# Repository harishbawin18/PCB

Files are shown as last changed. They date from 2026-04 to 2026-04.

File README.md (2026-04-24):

# PPG Watch PCB Design 

## Project Overview

This project presents the design and routing of a **Photoplethysmography (PPG) based wearable watch PCB**, developed using **KiCad 9.0**.
The PCB is designed to acquire pulse signals using an optical PPG sensor and support wearable health monitoring applications.
---
## Key Features
* Compact **wearable watch-size PCB layout**
* Designed using **KiCad 9.0**
* **Single-layer component placement**
* **Multi-layer routing** for optimized signal flow
* Clear **reference designators** (U1, R1, C1, etc.)
* Dedicated **power management section**
* Sensor integration for **PPG signal acquisition**
* Optimized routing for **noise reduction**
* Organized schematic hierarchy
---
## System Description
The PPG watch system includes the following major functional blocks:
### 1. PPG Sensor Module

* Optical PPG sensor detects blood volume changes.
* Uses LED light reflection technique.
* Generates analog signals corresponding to pulse rate.

### 2. Power Management Circuit

* Provides regulated voltage to all modules.
* Includes filtering capacitors for noise reduction.
* Ensures stable operation of sensor and processing units.

### 3. Processing Unit

* Microcontroller interface for signal acquisition.
* Processes raw PPG signals.
* Enables communication with external systems.

### 4. PCB Layout Design

* Compact layout suitable for wearable form factor.
* Optimized component placement for shorter routing paths.
* Ground routing designed to reduce noise interference.

---

## Design Tools Used

* **EDA Tool:** KiCad 9.0
* **PCB Design:** Schematic + Layout
* **Library Management:** Custom and standard KiCad libraries

---

## PCB Design Specifications

| Parameter | Value |
| --- | --- |
| PCB Tool | KiCad 9.0 |
| Layers Used | Multi-layer routing |
| Component Placement | Single-layer placement |
| Design Type | Wearable PCB |
| Application | Pulse Monitoring (PPG) |

---

## Files Included in Repository

* `.kicad_pro` — Project file
* `.kicad_sch` — Schematic design
* `.kicad_pcb` — PCB layout
* `.pretty` — Custom footprints
* Backup schematic references
* Supporting design files

---

## Design Considerations

The following engineering practices were followed during PCB development:

* Short routing paths to reduce signal delay
* Proper decoupling capacitor placement
* Organized power distribution
* Clear component labeling
* Noise-sensitive routing considerations
* Manufacturable PCB layout structure

---

## Applications

This PCB design can be used in:

* Wearable health monitoring devices
* Heart rate monitoring systems
* Biomedical signal acquisition systems
* Smart wearable electronics
* Embedded biomedical devices

---

## Learning Outcomes

Through this project, the following skills were developed:

* PCB schematic design
* Multi-layer PCB routing
* Component placement optimization
* Power and signal integrity considerations
* Wearable PCB design techniques
* KiCad professional workflow
* Hardware documentation practices

---

## Future Improvements

Possible future enhancements include:

* Integration with wireless communication (BLE)
* Battery charging circuit addition
* Sensor accuracy improvements
* Miniaturized PCB version
* Enclosure design for wearable deployment

---

## Author

**Harish Bawin**
Electronics and Communication Engineering (ECE)
PCB Design | Embedded Systems | Hardware Development

---

## License

This project is intended for educational and learning purposes.

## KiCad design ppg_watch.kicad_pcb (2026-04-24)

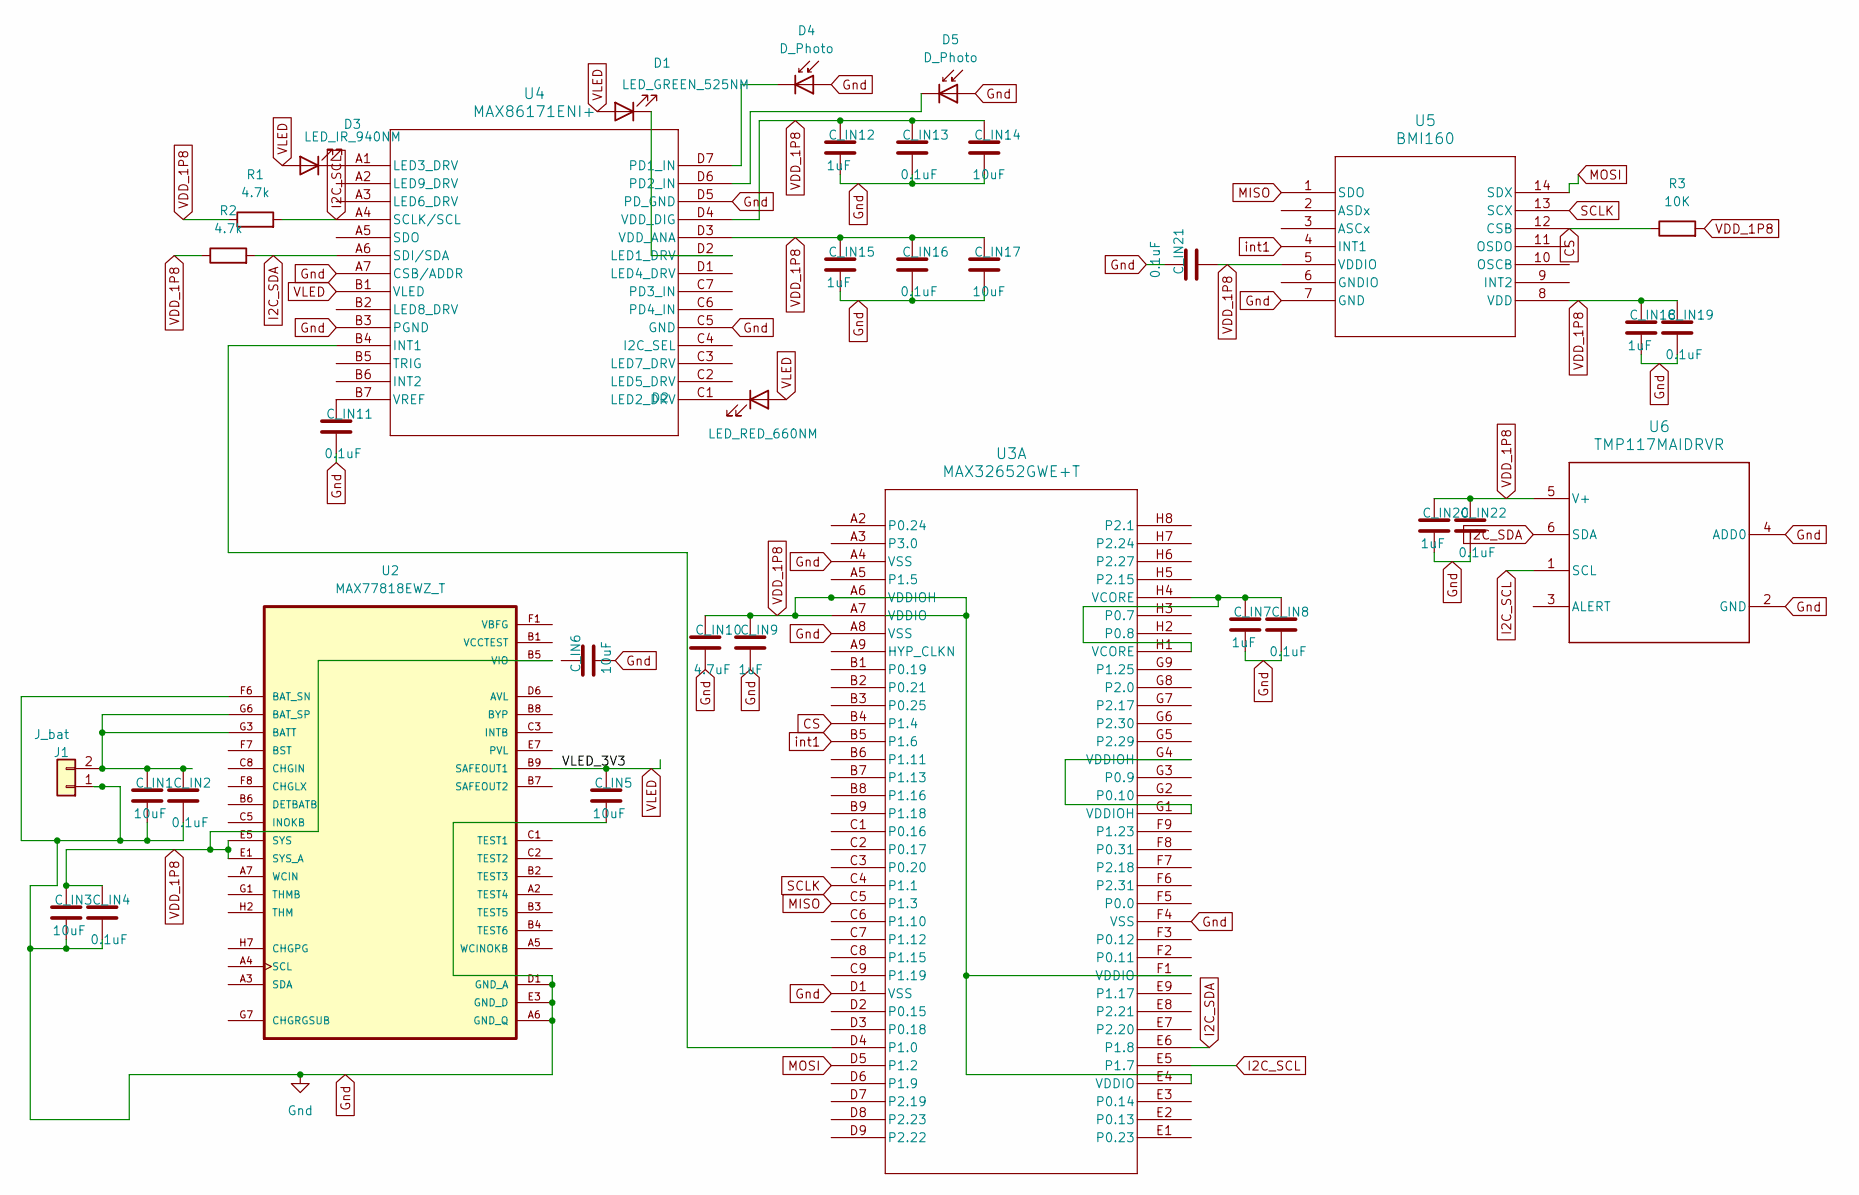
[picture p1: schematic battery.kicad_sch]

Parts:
C_IN1, C_IN3, C_IN5, C_IN6, C_IN14, C_IN17: 10uF; C_01005_0402Metric
C_IN2, C_IN4, C_IN8, C_IN11, C_IN13, C_IN16, C_IN19, C_IN21, C_IN22: 0.1uF; C_01005_0402Metric
C_IN7, C_IN9, C_IN12, C_IN15, C_IN18, C_IN20: 1uF; C_01005_0402Metric
C_IN10: 4.7uF; C_01005_0402Metric
D1: LED_GREEN_525NM; LED_0402_1005Metric
D2: LED_RED_660NM; LED_0402_1005Metric
D3: LED_IR_940NM; LED_0402_1005Metric
D4, D5: D_Photo; D_0603_1608Metric
J1: J_bat; JST_SH_SM02B-SRSS-TB_1x02-1MP_P1.00mm_Horizontal
R1, R2: 4.7k; R_0402_1005Metric
R3: 10K; R_0402_1005Metric
U2: MAX77818EWZ_T; BGA72N40P9X8_386X360X69N
U3: MAX32652GWE+T; 21-100219C_W1404A4&plus_1_MXM
U4: MAX86171ENI+; 21-100259_N281A2&plus_1_MXM
U5: BMI160; LGA_BMI3X2P5_BOS
U6: TMP117MAIDRVR; DRV0006B

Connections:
CS: R3.1, U3.B4 (P1.4), U5.12 (CSB)
Gnd: C_IN1.2, C_IN2.2, C_IN3.2, C_IN4.2, C_IN5.2, C_IN6.2, C_IN7.2, C_IN8.2, C_IN9.2, C_IN10.2, C_IN11.2, C_IN12.2, C_IN13.2, C_IN14.2, C_IN15.2, C_IN16.2, C_IN17.2, C_IN18.2, C_IN19.2, C_IN20.2, C_IN21.1, C_IN22.2, D4.2 (A), D5.2 (A), J1.1, U2.A6 (GND_Q), U2.D1 (GND_A), U2.D2 (GND_A), U2.D3 (GND_A), U2.D4 (GND_A), U2.D5 (GND_A), U2.E3 (GND_D), U2.F6 (BAT_SN), U3.A4 (VSS), U3.A8 (VSS), U3.D1 (VSS), U3.F4 (VSS), U4.A7 (CSB/ADDR), U4.B3 (PGND), U4.C5 (GND), U4.D5 (PD_GND), U5.7 (GND), U6.2 (GND), U6.4 (ADD0); also elsewhere on the board
I2C_SCL: R1.2, U3.E5 (P1.7), U4.A4 (SCLK/SCL), U6.1 (SCL)
I2C_SDA: R2.2, U3.E6 (P1.8), U4.A6 (SDI/SDA), U6.6 (SDA)
MISO: U3.C5 (P1.3), U5.1 (SDO)
MOSI: U3.D5 (P1.2), U5.14 (SDX)
unnamed: C_IN7.1, C_IN8.1, U3.H1 (VCORE), U3.H4 (VCORE)
unnamed: D1.1 (K), U4.D2 (LED1_DRV)
unnamed: D2.1 (K), U4.C1 (LED2_DRV)
unnamed: D3.1 (K), U4.A1 (LED3_DRV)
unnamed: D4.1 (K), U4.D7 (PD1_IN)
unnamed: D5.1 (K), U4.D6 (PD2_IN)
unnamed: C_IN1.1, C_IN2.1, J1.2, U2.G3 (BATT), U2.G4 (BATT), U2.G6 (BAT_SP), U2.H3 (BATT), U2.H4 (BATT)
unnamed: U2.B8 (BYP), U2.C7 (BYP), U2.D7 (BYP), U2.E8 (BYP), U2.E9 (BYP)
unnamed: U2.C8 (CHGIN), U2.C9 (CHGIN), U2.D8 (CHGIN), U2.D9 (CHGIN)
unnamed: U2.F8 (CHGLX), U2.F9 (CHGLX), U2.G8 (CHGLX), U2.G9 (CHGLX)
unnamed: U2.H7 (CHGPG), U2.H8 (CHGPG), U2.H9 (CHGPG)
unnamed: U2.A7 (WCIN), U2.A8 (WCIN)
unnamed: U3.D4 (P1.0), U4.B4 (INT1)
unnamed: U3.G1 (VDDIOH), U3.G4 (VDDIOH)
unnamed: C_IN11.1, U4.B7 (VREF)
SCLK: U3.C4 (P1.1), U5.13 (SCX)
VDD_1P8: C_IN3.1, C_IN4.1, C_IN9.1, C_IN10.1, C_IN12.1, C_IN13.1, C_IN14.1, C_IN15.1, C_IN16.1, C_IN17.1, C_IN18.1, C_IN19.1, C_IN20.1, C_IN21.2, C_IN22.1, R1.1, R2.1, R3.2, U2.B5 (VIO), U2.E1 (SYS_A), U2.E5 (SYS), U2.F2 (SYS_A), U2.F5 (SYS), U2.G5 (SYS), U2.H5 (SYS), U2.H6 (SYS), U3.A6 (VDDIOH), U3.A7 (VDDIO), U3.E4 (VDDIO), U3.F1 (VDDIO), U4.D3 (VDD_ANA), U4.D4 (VDD_DIG), U5.5 (VDDIO), U5.8 (VDD), U6.5 (V+); also elsewhere on the board
VLED: C_IN5.1, D1.2 (A), D2.2 (A), D3.2 (A), U2.B9 (SAFEOUT1), U4.B1 (VLED)
int1: U3.B5 (P1.6), U5.4 (INT1)

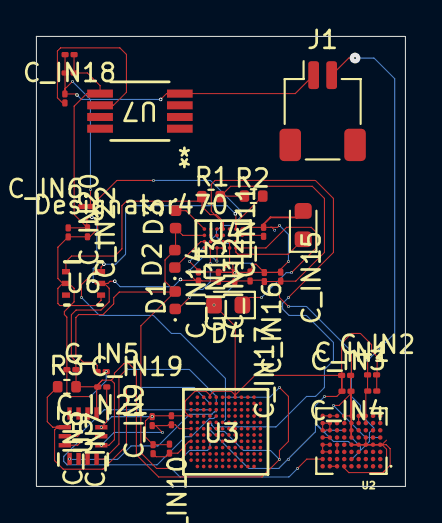
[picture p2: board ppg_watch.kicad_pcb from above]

Board: 2 copper layers, 20.5 x 25.0 mm, 39 parts (0 on the bottom side), 26 nets.

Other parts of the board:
C_IN23, C_IN24: 0.1uF; C_01005_0402Metric
U7: AD8237ARMZ; RM_8_ADI

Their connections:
Gnd: C_IN23.2, C_IN24.2, U7.4 (-VS); also elsewhere on the board
unnamed: C_IN24.1, U7.6 (REF)
VDD_1P8: C_IN23.1, U7.5 (+VS); also elsewhere on the board

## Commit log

2026-04-24 Added PPG Watch PCB files
    [battery.kicad_sch, power_pmic.kicad_sch, ppg.kicad_sch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]
2026-04-24 Add README.md for PPG Watch PCB Design project
    Added detailed project overview, features, system description, design tools, specifications, applications, learning outcomes, future improvements, author information, and license.
